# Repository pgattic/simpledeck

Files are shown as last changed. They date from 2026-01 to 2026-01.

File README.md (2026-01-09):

# SimpleDeck

A Glueless, Solderless Raspberry Pi 4 Cyberdeck

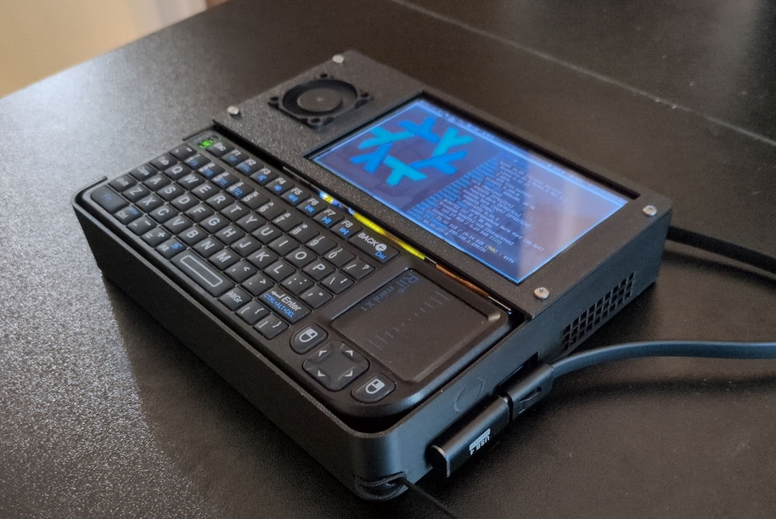
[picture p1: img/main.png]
Main image of cyberdeck


## Features

- Removable wireless keyboard + touchpad
- 6+ hours of battery life
- Touchscreen display
- Active cooling
- Simple, non-destructive assembly
- Power cable doubles as lanyard

| Exposes all the main Raspberry Pi ports | Suitable for lightweight gaming | Portable! |
| - | - | - |
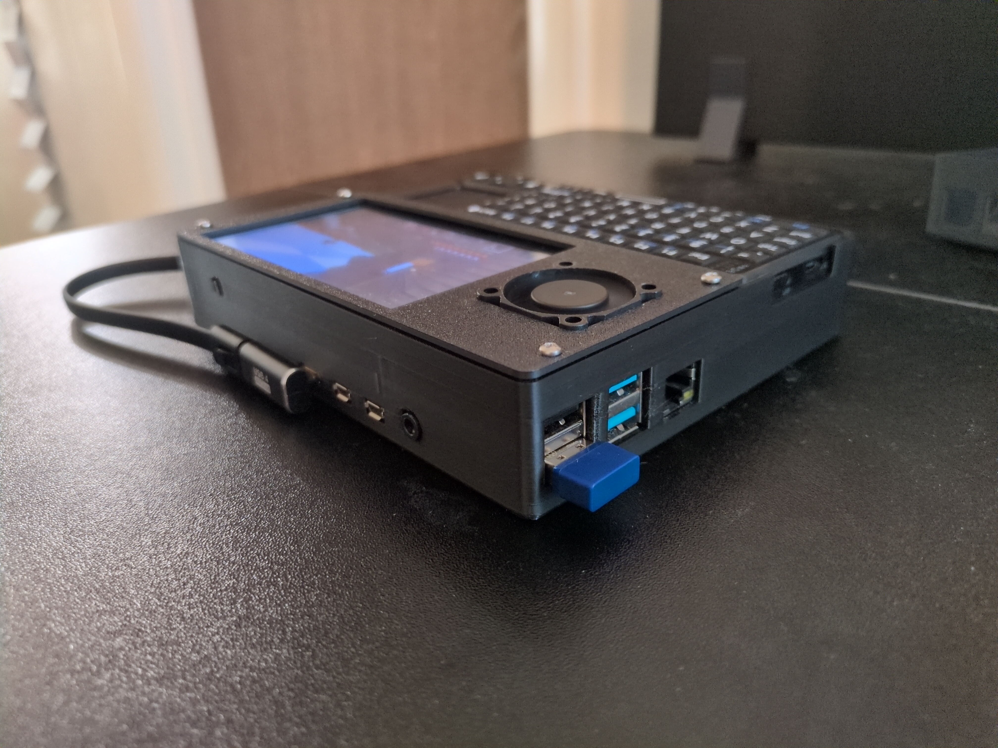
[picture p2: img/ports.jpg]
Exposed RPi4 Ports
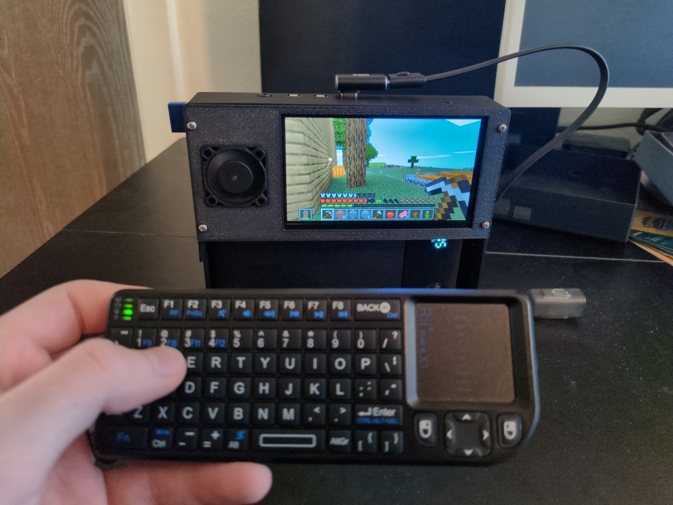
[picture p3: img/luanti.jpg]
Luanti gaming
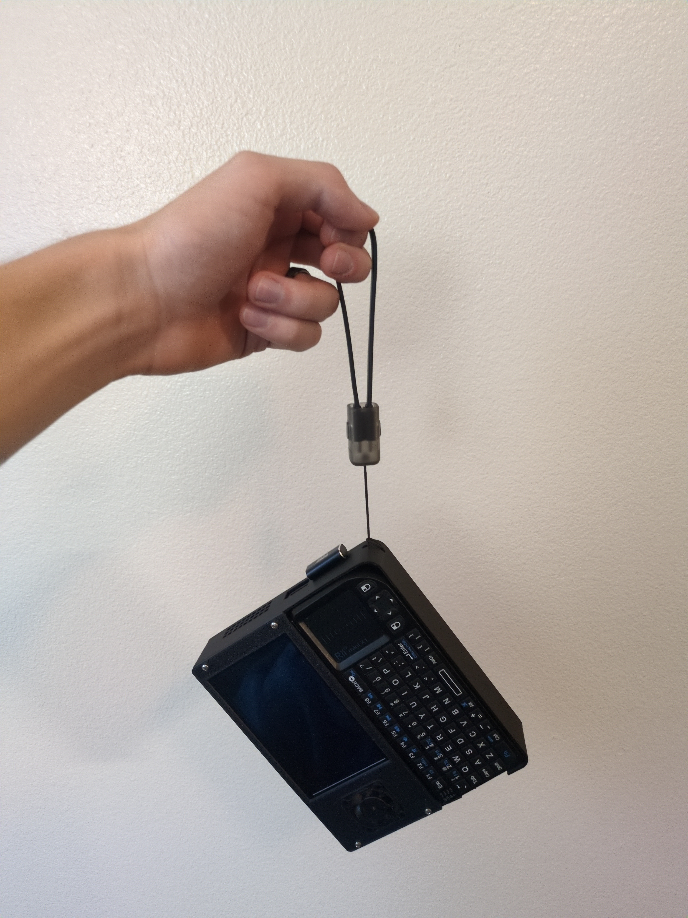
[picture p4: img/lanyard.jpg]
Cable serving as lanyard
|  |  |  |

## Parts required

- Raspberry Pi 4 Model B
- Miniature 5V Cooling Fan \[[link](https://www.adafruit.com/product/4468)\]
- 4.3 Inch 800x480 DSI Touch Screen \[[link](https://www.aliexpress.com/item/3256807896146352.html)\]
- Rii X1 2.4GHz Mini Wireless Keyboard (be sure to select the correct language/layout for your needs!) \[[link](https://www.aliexpress.com/item/3256804879544433.html)\]
- Anker 10,000mAh, 22.5W Power Bank (Note that this one is 6 inches long! Newer models are smaller and their ports are arranged slightly different) \[[link](https://www.bestbuy.com/product/anker-power-bank-10000mah-22-5w-black/JJ858RCW2K/)\]
- Two 90-degree USB-C adapters \[[link](https://www.amazon.com/gp/product/B0BNMDRWR6)\]
- Four M2x8mm screws

## Assembly Instructions

1. Gather parts, 3D print box and lid
2. Slide the Pi into the port holes, snap it down onto the lower support beams
3. Slide battery in, upper edge first
4. Connect fan and display to Pi with their respective cables and ports
5. Fit fan into place on the lid, set display into the shelves found on the inside of the box
6. Screw lid onto case
7. Connect wireless keyboard dongle to any USB port on Pi, set keyboard into place
8. Connect USB-C angle adapters and thread lanyard through battery

## Dev Instructions

- `nix develop`
- `openscad src/box.scad`

## Software

- The case was modeled using [OpenSCAD](https://openscad.org/)
- My NixOS configuration for the Raspberry Pi itself can be found in my [dotfiles repository](https://github.com/pgattic/dotfiles/tree/main/hosts/cyberpi), but Raspberry Pi OS works perfectly fine.

## Thanks

- [chrisicksix](https://makerworld.com/en/@chrisicksix) on MakerWorld for sharing your [cyberdeck](https://makerworld.com/en/models/1440390-cyberdeck-raspberry-pi-4-5). I started by printing your shell, and then decided I would model my own with a similar but more complex design
- BambuLabs for making 3D printing simple and accessible
- OpenSCAD for making CAD so simple for software nerds

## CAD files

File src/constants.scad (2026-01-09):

// All lengths in millimeters

BATTERY_LENGTH = 71.50;
BATTERY_THICKNESS = 16.20;
BATTERY_WIDTH = 152.00;

KEYBOARD_THICKNESS = 12.00;
KEYBOARD_WIDTH = 153.00;
KEYBOARD_LENGTH = 59.00;

WALL_THICKNESS = 1.60;

RPI_BOTTOM_CLEARANCE = 2.3;
RPI_PCB_THICKNESS = 1.5;
RPI_LENGTH = 56.50;
RPI_HOLE_HEIGHT = RPI_BOTTOM_CLEARANCE + RPI_PCB_THICKNESS;

BOX_WIDTH = BATTERY_WIDTH;
BOX_LENGTH = BATTERY_LENGTH + RPI_LENGTH;
BOX_HEIGHT = BATTERY_THICKNESS + KEYBOARD_THICKNESS;
BOX_DIMENSIONS = [BOX_WIDTH, BOX_LENGTH, BOX_HEIGHT];
BOX_CORNERS = [1.5, 1.5, 6, 8];

DISPLAY_WIDTH = 106;
DISPLAY_LENGTH = 68;
DISPLAY_SUPPORT_RAD = 3;

module round_prism(dimensions, radii) {
  assert(is_list(dimensions) && len(dimensions) == 3, "'dimensions' must be of the pattern [w, l, h]!");
  assert(is_list(radii) && len(radii) == 4, "'radii' must be of the pattern [fl, fr, bl, br]!");
  w = dimensions[0];
  l = dimensions[1];
  h = dimensions[2];
  eps = 0.001;
  fl = max(radii[0], eps);
  fr = max(radii[1], eps);
  bl = max(radii[2], eps);
  br = max(radii[3], eps);

  fn = 64;
  hull() {
    translate([bl, bl, 0]) cylinder(h, r=bl, $fn=fn); // bl
    translate([w-br, br, 0]) cylinder(h, r=br, $fn=fn); // br
    translate([fl, l-fl, 0]) cylinder(h, r=fl, $fn=fn); // fl
    translate([w-fr, l-fr, 0]) cylinder(h, r=fr, $fn=fn); // fr
  }
}

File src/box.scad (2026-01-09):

include <constants.scad>

module bottom_dome(radius) {
  difference() {
    sphere(radius, $fn=24);
    translate([-radius, -radius, 0]) cube([radius*2, radius*2, radius]);
  }
}

module round_box(dimensions, radii, wall_thickness) {
  difference() {
    minkowski() {
      round_prism(dimensions, radii);
      bottom_dome(wall_thickness);
    }
    round_prism([dimensions[0], dimensions[1], dimensions[2]+0.1], radii);
  }
}

module rpi_support(through_nub = true) {
  cylinder(RPI_BOTTOM_CLEARANCE, r=2.9, $fn=24);
  if (through_nub) {
    translate([0, 0, RPI_BOTTOM_CLEARANCE]) cylinder(2, r=1.15, $fn=24);
  }
}

module display_shelf() {
  fn = 64;
  outer_rad = 4;
  inner_rad = 3;
  height = 12;
  taper = 8;

  translate([0, -inner_rad, 0]) difference() {
    translate([0, 0, -height]) union() {
      cylinder(height, r=outer_rad, $fn=fn);
      translate([-outer_rad, 0, 0]) cube([outer_rad*2, outer_rad, height]);
    }
    translate([0, 0, -height]) polyhedron(
      points = [
        [-outer_rad, -outer_rad, taper],
        [ outer_rad, -outer_rad, taper],
        [-outer_rad, -outer_rad, 0],
        [ outer_rad, -outer_rad, 0],
        [-outer_rad,  outer_rad, 0],
        [ outer_rad,  outer_rad, 0]
      ],
      faces = [
        [0, 1, 2], [2, 1, 3],
        [1, 0, 4], [1, 4, 5],
        [0, 2, 4],
        [3, 1, 5],
        [2, 3, 4], [4, 3, 5]
      ]
    );
    translate([0, 0, -height]) cylinder(height, r=inner_rad, $fn=fn);
  }
}

/// A side-mounted hole to drive a screw through
module screw_hole() {
  fn = 24;
  h = 4;
  o_rad = 2;
  i_rad = 1;
  translate([0, -o_rad, -h]) difference() {
    union() {
      cylinder(h, r=o_rad, $fn=fn);
      translate([-o_rad * 2, 0, 0]) cube([o_rad * 4, o_rad, h]);
    }
    cylinder(h, r=i_rad, $fn=fn);
    translate([o_rad + o_rad, 0, 0]) cylinder(h, r=o_rad, $fn=fn);
    translate([-o_rad - o_rad, 0, 0]) cylinder(h, r=o_rad, $fn=fn);
    // translate([-o_rad, i_rad, 0]) cube([o_rad*2, o_rad-i_rad, h]);
  }
}

/// Holes for RPi's USB and ethernet ports
module left_holes() {
  translate([0, RPI_HOLE_HEIGHT+1.5]) {
    translate([3,   0]) square([13, 14.3]);
    translate([21,  0]) square([13, 14.3]);
    translate([40, -1]) square([13, 11]);
  }
  translate([BOX_LENGTH - KEYBOARD_LENGTH + 14, BOX_HEIGHT-7]) offset(r = 1.6, $fn=24) square([28, 7]);
}

module vent_holes() {
  grid_width = 9;
  grid_height = 3;
  square_size = 3;
  square_spacing = 4;

  for (x = [0 : square_spacing : (grid_width-1) * square_spacing]) {
      for (y = [0 : square_spacing : (grid_height-1) * square_spacing]) {
          translate([x, y])
              square(square_size);
      }
  }
}

/// Holes for power bank's ports
module right_holes() {
  translate([21.5, BATTERY_THICKNESS / 2]) offset(r = 3.5, $fn=24) square([6, 0.001]);
  translate([55, BATTERY_THICKNESS / 2]) square([17.5, 10], center=true);
  translate([76, 2.5]) vent_holes();
}

/// Holes for other RPi ports
module back_holes() {
  offset(r = 0.2) // This makes the holes a tiny bit bigger so the ports line up easier
  scale([-1, 1]) {
    translate([0, RPI_HOLE_HEIGHT]) {
      translate([34.4, 3.265]) circle(3.265, $fn=24);
      translate([45.2, -0.5]) square([7.2, 3.8]);
      translate([58.7, -0.5]) square([7.2, 3.8]);
      translate([74, 1.6]) offset(r = 1.8, $fn=24) square([6, 0.001]);
    }
    // Button for brightness
    translate([126, BOX_HEIGHT - 10]) scale([.6, -.5]) text("U", halign="center", valign="center");
  }
}

module bottom_shell() {

  difference() {
    round_box(BOX_DIMENSIONS, BOX_CORNERS, WALL_THICKNESS);

    translate([0, BOX_LENGTH, 0]) rotate([90, 0, -90]) linear_extrude(WALL_THICKNESS)
      left_holes();
    translate([BOX_WIDTH, 0, 0]) rotate([90, 0, 90]) linear_extrude(WALL_THICKNESS)
      right_holes();
    translate([0, BOX_LENGTH, 0]) rotate([90, 0, 180]) linear_extrude(WALL_THICKNESS)
      back_holes();
    translate([126, BOX_LENGTH-2, BOX_HEIGHT-10]) sphere(r=2.5, $fn=24);

    translate([BOX_WIDTH+1, 34, BATTERY_THICKNESS+3]) rotate([0, -90, 0]) cylinder(r=5, 3, $fn=24);
    // Lanyard hole
    translate([BOX_WIDTH, 0, BATTERY_THICKNESS/2]) rotate_extrude() {
        translate([6, 0, 0]) {
            circle(r = 2, $fn=24);
        }
    }
  }
  // Shelves to hold the display
  shelf_center_dist = 99.7;
  translate([43,  BOX_LENGTH, BOX_HEIGHT - 7.8]) display_shelf();
  translate([43 + shelf_center_dist, BOX_LENGTH, BOX_HEIGHT - 7.8]) display_shelf();

  // Supports to hold the Pi above the floor
  pi_screw_width = 48.8;
  pi_screw_length = 57.7;
  translate([27, BOX_LENGTH - 3.8,  0]) rpi_support(false);
  translate([27, BOX_LENGTH - 3.8 - pi_screw_width, 0]) rpi_support();
  translate([27 + pi_screw_length, BOX_LENGTH - 3.8,  0]) rpi_support(false);
  translate([27 + pi_screw_length, BOX_LENGTH - 3.8 - pi_screw_width, 0]) rpi_support();

  // Holes for face plate screws
  screwhole_height = BOX_HEIGHT - 3;
  translate([BOX_WIDTH, BOX_LENGTH - 8, screwhole_height]) rotate([0, 0, -90]) screw_hole();
  translate([0, BOX_LENGTH - 8, screwhole_height]) rotate([0, 0, 90]) screw_hole();
  translate([BOX_WIDTH, BOX_LENGTH - DISPLAY_LENGTH + 8, screwhole_height]) rotate([0, 0, -90]) screw_hole();
  translate([0, BOX_LENGTH - DISPLAY_LENGTH + 8, screwhole_height]) rotate([0, 0, 90]) screw_hole();

  // Small indent to make up width difference between battery and keyboard
  translate([0, 24, 0]) cube([0.5, 24, BATTERY_THICKNESS*0.7]);
}

bottom_shell();

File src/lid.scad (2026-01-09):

include <constants.scad>

// This was very quickly thrown together, and I definitely could clean it up.
// But I won't right now. I think it'll work.

LID_LENGTH = DISPLAY_LENGTH;
FAN_WIDTH = 30;
RAIL_HEIGHT = 4;

module lid() {
  difference() {
    union() {
      // Main slab
      translate([-WALL_THICKNESS, 0, 0])
        round_prism(
          [BOX_WIDTH + WALL_THICKNESS*2, LID_LENGTH + WALL_THICKNESS, WALL_THICKNESS],
          [BOX_CORNERS[0]+WALL_THICKNESS, BOX_CORNERS[1]+WALL_THICKNESS, 0, 0]
        );

      // Rails
      cube([WALL_THICKNESS, LID_LENGTH - 2, RAIL_HEIGHT]);
      translate([BOX_WIDTH - WALL_THICKNESS, 0, 0]) cube([WALL_THICKNESS, LID_LENGTH - 2, RAIL_HEIGHT]);

      // Cylinders for screw holes
      translate([2, 8, 0]) cylinder(RAIL_HEIGHT, r=2, $fn=24);
      translate([2, DISPLAY_LENGTH - 8, 0]) cylinder(RAIL_HEIGHT, r=2, $fn=24);
      translate([BOX_WIDTH - 2, 8, 0]) cylinder(RAIL_HEIGHT, r=2, $fn=24);
      translate([BOX_WIDTH - 2, DISPLAY_LENGTH - 8, 0]) cylinder(RAIL_HEIGHT, r=2, $fn=24);
    }
    // Window for display
    translate([9, 6, 0]) cube([100, 60, WALL_THICKNESS]);
    // Hole for fan
    translate([117, 20, 0]) round_prism([FAN_WIDTH, FAN_WIDTH, WALL_THICKNESS], [2.5, 2.5, 2.5, 2.5]);

    // Screw holes
    translate([2, 8, 0]) cylinder(RAIL_HEIGHT, r=1, $fn=24);
    translate([2, DISPLAY_LENGTH - 8, 0]) cylinder(RAIL_HEIGHT, r=1, $fn=24);
    translate([BOX_WIDTH - 2, 8, 0]) cylinder(RAIL_HEIGHT, r=1, $fn=24);
    translate([BOX_WIDTH - 2, DISPLAY_LENGTH - 8, 0]) cylinder(RAIL_HEIGHT, r=1, $fn=24);
  }
}

lid();

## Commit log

2025-11-21 First commit - 1st attempt for box bottom
    [bottom.FCStd]
2025-11-22 Second print... Holes are still not lined up quite right
    [bottom.FCStd]
2025-12-25 Rewrite in OpenSCAD!
    [bottom.FCStd, box.scad]
2025-12-25 Add RPi supports and display shelf
    These both need measurements to verify position
    [box.scad]
2025-12-26 Fix STL exporting, remove non-required epsilons
    I know this will make the preview look ugly, but actually rendering the
    model looks fine, and that's what matters.
    [box.scad]
2025-12-27 Go through and measure everything
    [box.scad]
2025-12-28 Add a bunch of stuff
    [box.scad]
2025-12-29 Tweaks made for Third Print
    Added hole for lanyard
    [box.scad]
2025-12-30 Adjust dimensions after third print
    [box.scad]
2026-01-07 More tweaks after fourth print
    [box.scad]
2026-01-09 Separate some constants, create lid
    [box.scad, constants.scad, lid.scad]
2026-01-09 Final tweaks, add photos to README
    [box.scad]
